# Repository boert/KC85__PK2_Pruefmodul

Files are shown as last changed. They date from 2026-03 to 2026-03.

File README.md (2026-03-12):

# KC85__PK2_Pruefmodul
Nachentwickelte Leiterplatte zum Prüfmodul PK2 für den KC85/4 aus Mühlhausen.
Bisher ist der Leiterplattenentwurf nicht getestet worden (02/2026).

## Schaltplan
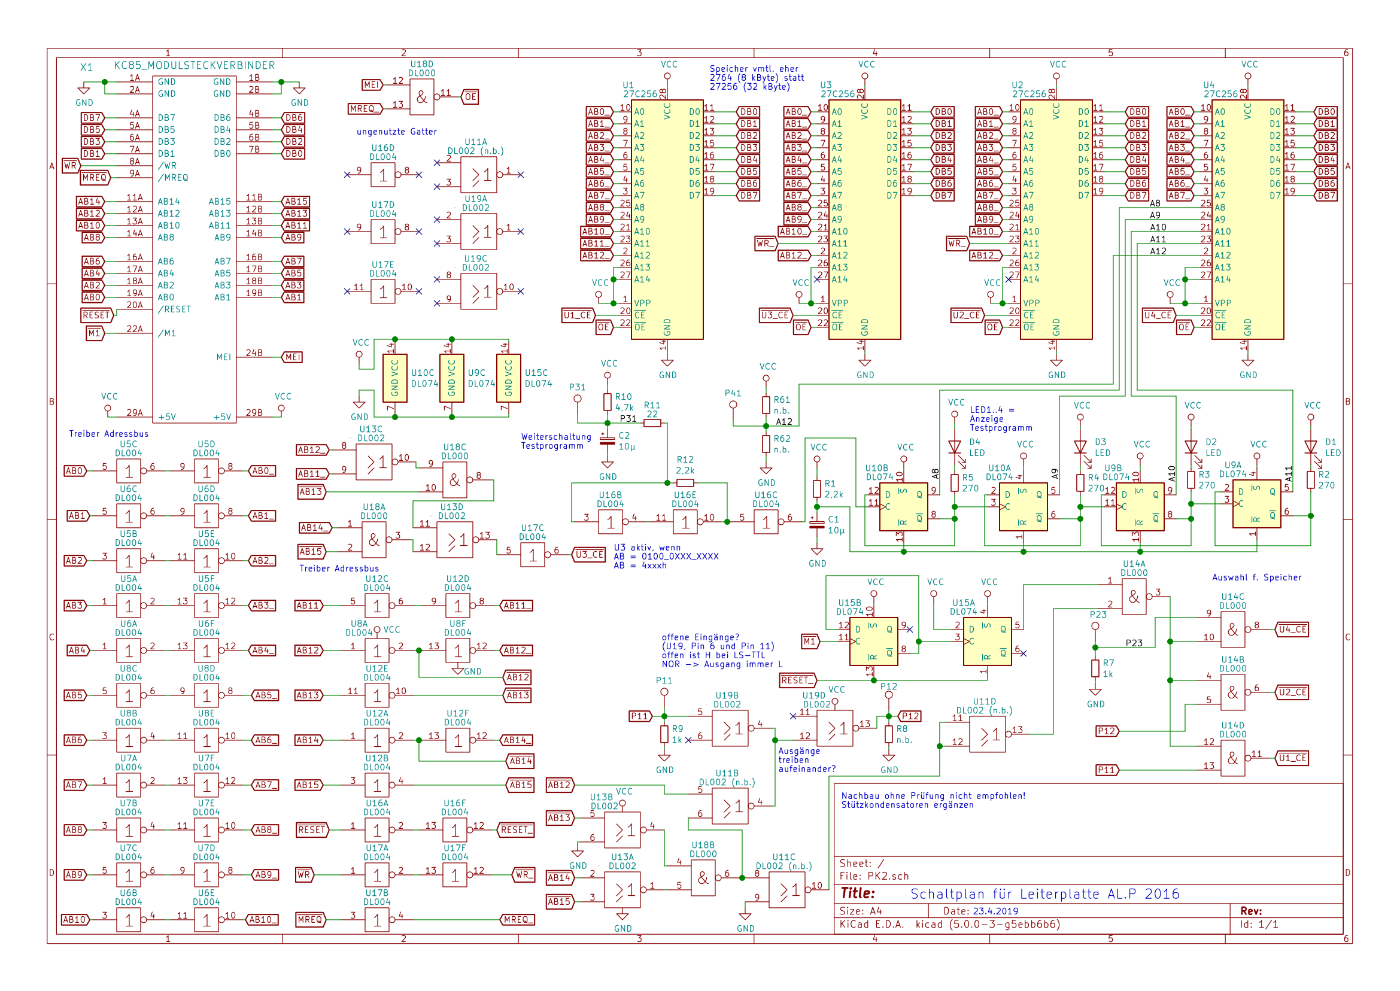
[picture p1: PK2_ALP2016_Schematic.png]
Schaltplan


## Layout
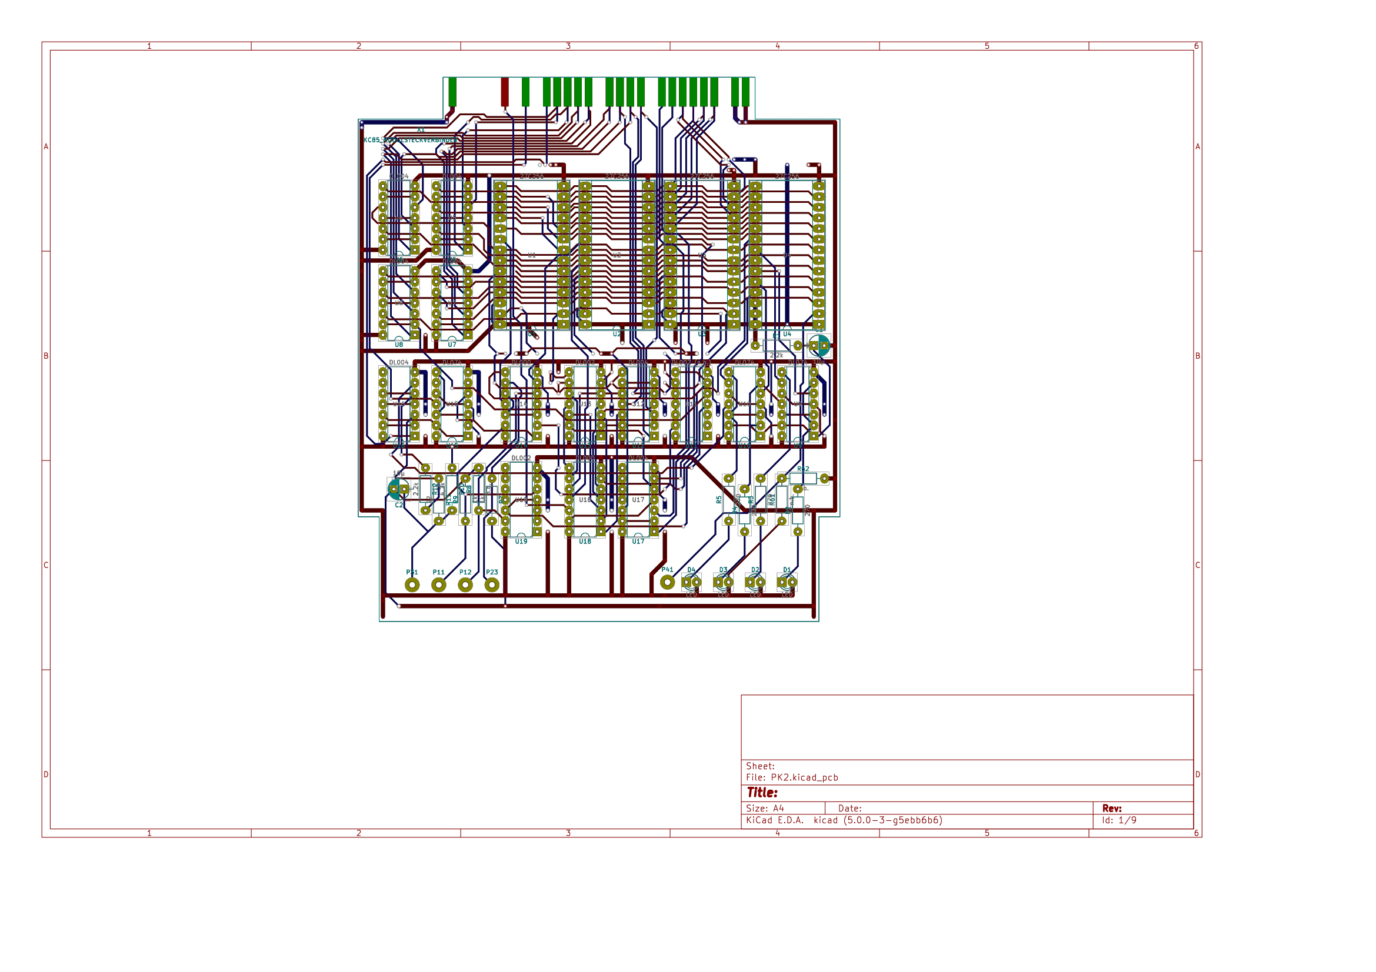
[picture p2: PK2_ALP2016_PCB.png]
Layout


## EPROMs
Ein EPROM enthält das Betriebssystem CAOS 4.2, das andere die 16 in der Anleitung beschriebenen Prüfprogramme.
Die Prüfsumme über den Speicherinhalt wird nach CRC-CCITT (CRC-16) [^1] berechnet:
```
$ jacksum -a crc:16,1021,ffff,false,false,0 -X *.BIN
79D5    8192    Pruefmodul_CAOS_42.BIN
3578    8192    Pruefmodul_P222.BIN
```

Vielen Dank an Andreas, Guido, KaiOr und Ralle für die Vorlagen!

[^1]: [Wikipedia, Zyklische Redundanzprüfung](https://de.wikipedia.org/wiki/Zyklische_Redundanzpr%C3%BCfung)

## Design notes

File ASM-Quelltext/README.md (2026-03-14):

# P222_neu.asm
Die Binärdatei 'P222.BIN' wurde rückübersetzt (Disassmbler[^1]). Zusammen mit den Marken und Kommentaren aus P1.ASM und P2.ASM wurde der Assmbler-Quellcode neu erstellt.
Als Assembler kommt z80asm[^2] zum Einsatz.

Ein Kontrolle der Prüfsummen[^3] ergibt Übereinstimmung mit dem Original:
```
make jacksum

jacksum -a crc:16,1021,ffff,false,false,0 -X ../EPROMs/Pruefmodul_P222.BIN P222_neu.rom
3578    8192    ../EPROMs/Pruefmodul_P222.BIN
3578    8192    P222_neu.rom
```

## Referenzen

[^1]: [Z80-Disassmbler](https://github.com/lvitals/z80dasm/)
[^2]: [Z80-Assembler z80asm](https://www.nongnu.org/z80asm/)
[^3]: [Jacksum, checksum untility](https://jacksum.net/en/index.html)

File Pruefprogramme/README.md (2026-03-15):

# Prüfprogramme

Die Prüfprogramme sind für die Inbetriebnahme des KC85/4 und zur Fehlersuche bei Hardwareproblemen entwickelt worden.
Manche Prüfprogramme (z.B. REGTEST) sind nur sinnvoll mit Messgeräten, wie z.B. einem Oszilloskop, zu gebrauchen.

Die hier abgelegten Prüfprogramme sind aus dem ROM P222.BIN herausgelöst und so angepasst, das direkt im KC lauffähig sind.

## BWS 55H
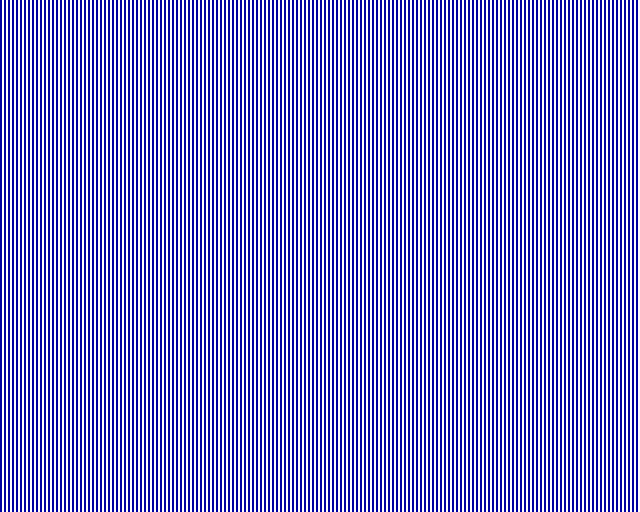
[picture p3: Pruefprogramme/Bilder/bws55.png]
BWS 55H


## Normaltestbild
Dieses Prüfprogramm ermöglicht eine allgemeine Beurteilung
der Farb- sowie Grafiktüchtigkeit des Gerätes.
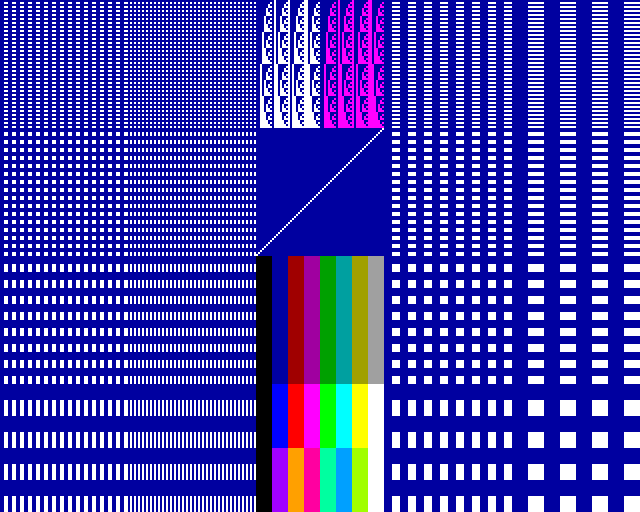
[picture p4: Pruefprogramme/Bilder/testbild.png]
Normaltestbild


## Pixeltestbild
Hier erfolgt eine Darstellung im hochauflösenden Pixelmode des
KC 85/4.
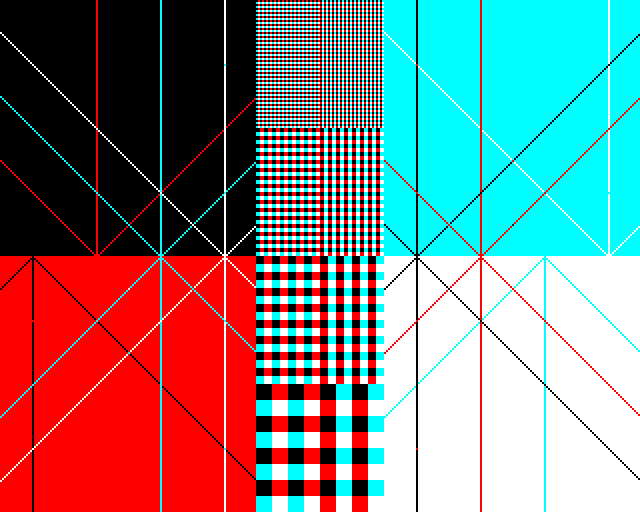
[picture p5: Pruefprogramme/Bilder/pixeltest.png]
Pixeltestbild


## Farbbalken
Dieses Prüfprogramm dient zum Feststellen von Fehlern auf der
Video-Leiterplatte.
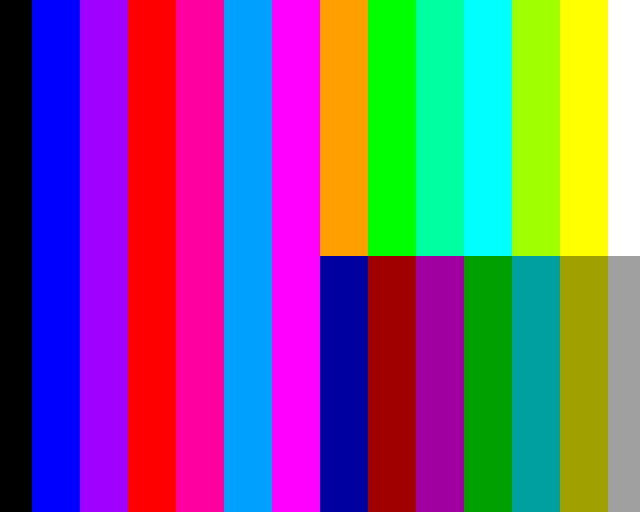
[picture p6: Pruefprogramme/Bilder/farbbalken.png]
Farbbalken


Zum Vergleich das resultierende FBAS-Signal mit dem Oszilloskop aufgenommen:
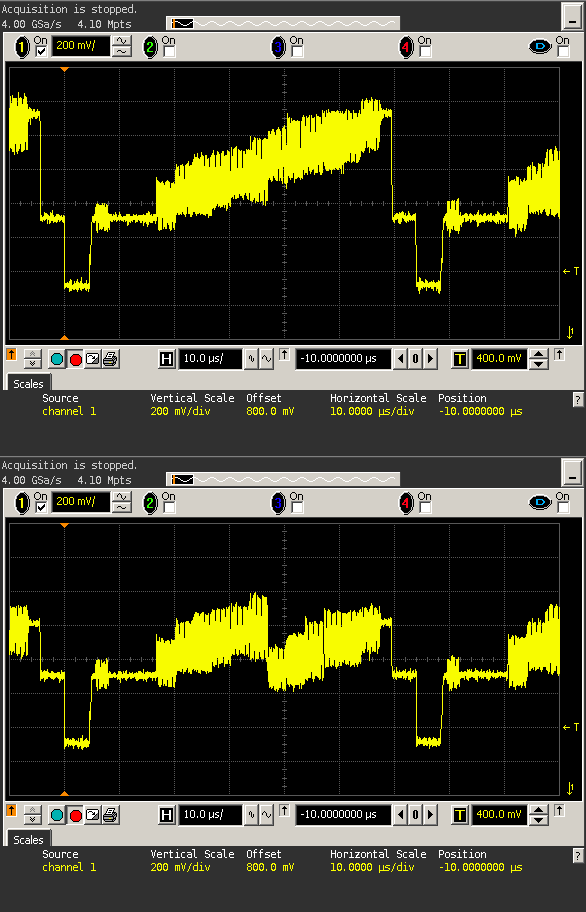
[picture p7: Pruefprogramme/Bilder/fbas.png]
FBAS-Signal


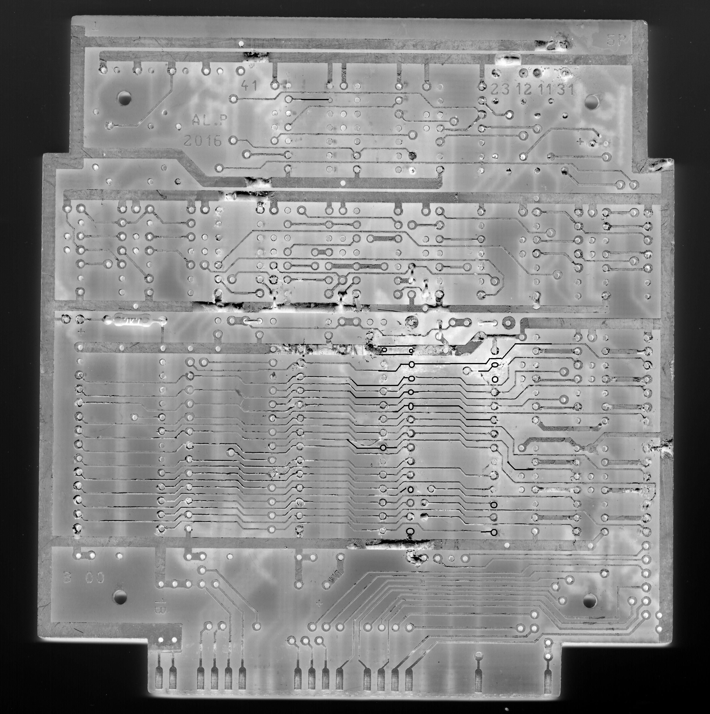
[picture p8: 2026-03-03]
Bilder/Platine_P2016_LS.jpg

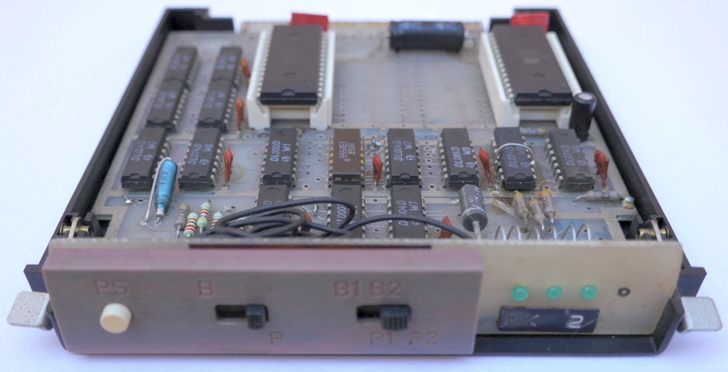
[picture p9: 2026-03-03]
Bilder/Modul_PK2_vorn.jpg

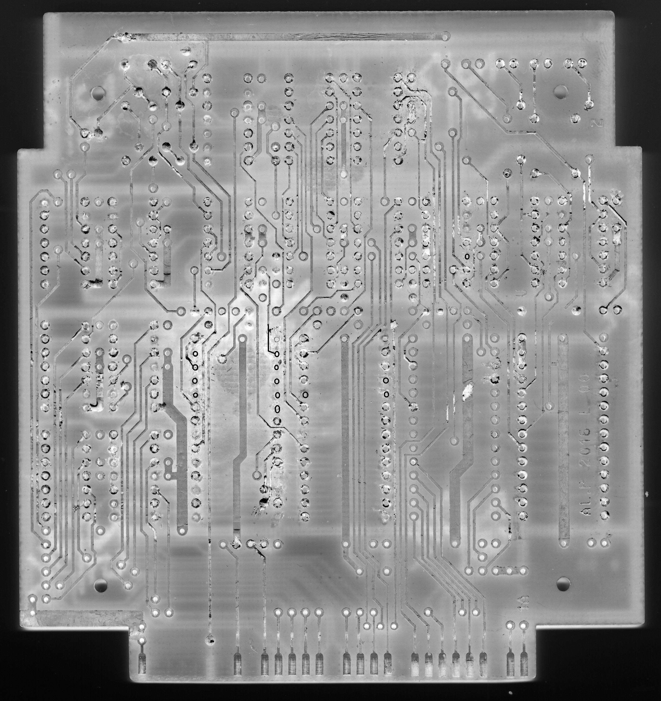
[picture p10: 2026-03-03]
Bilder/Platine_P2016_BS.jpg

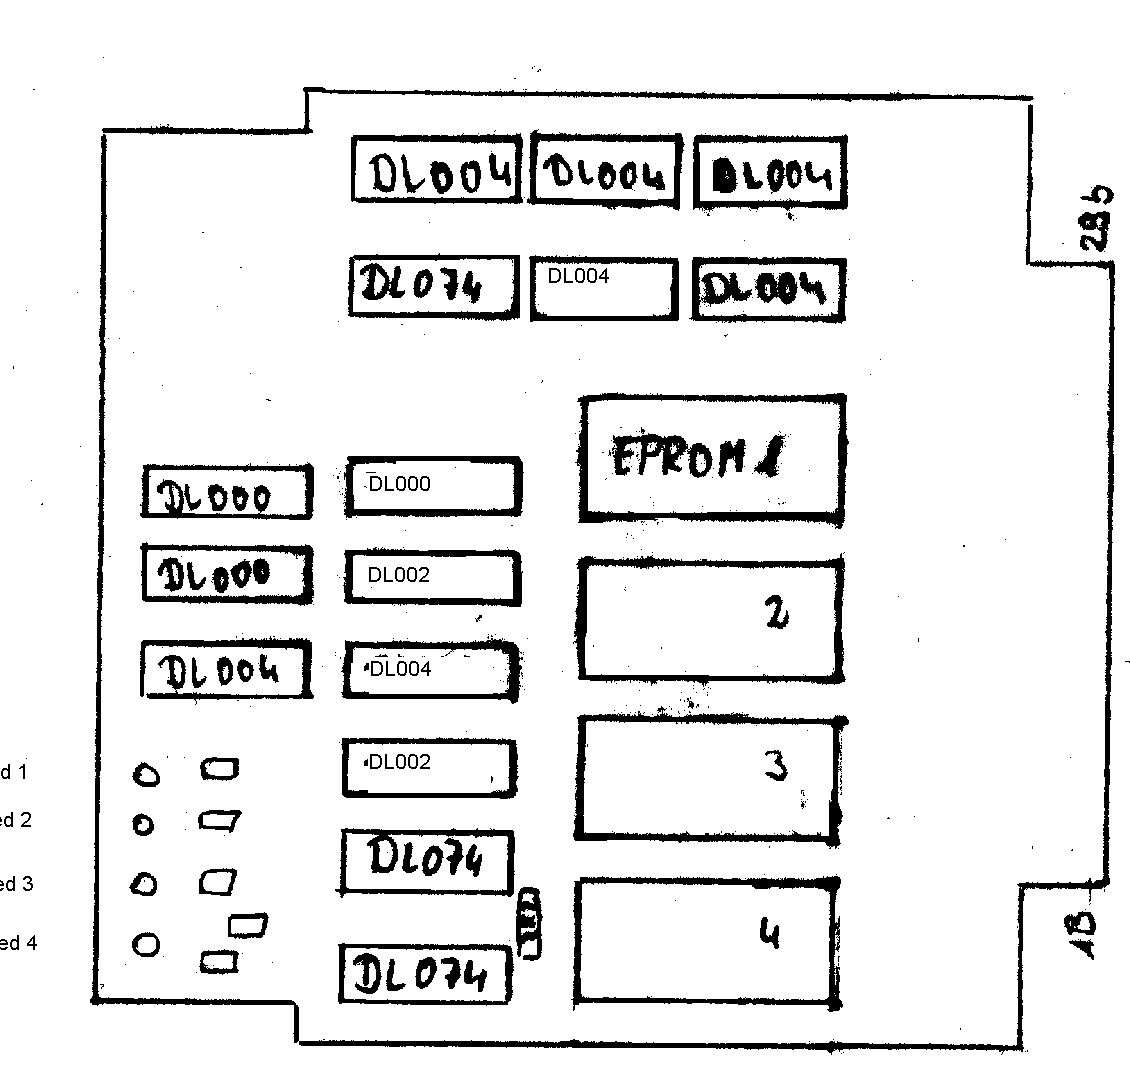
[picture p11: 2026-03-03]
Bilder/Bestueckungsplan.jpg

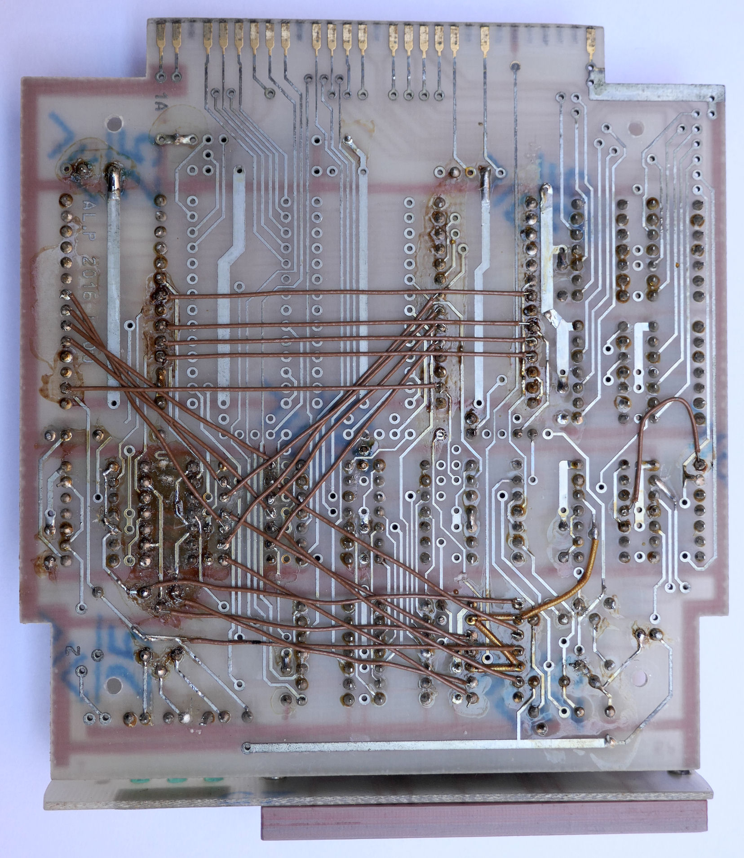
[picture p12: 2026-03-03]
Bilder/Modul_PK2_unten.jpg

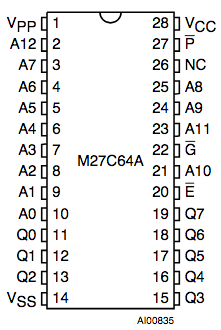
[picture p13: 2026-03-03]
kicad/M27C64.png

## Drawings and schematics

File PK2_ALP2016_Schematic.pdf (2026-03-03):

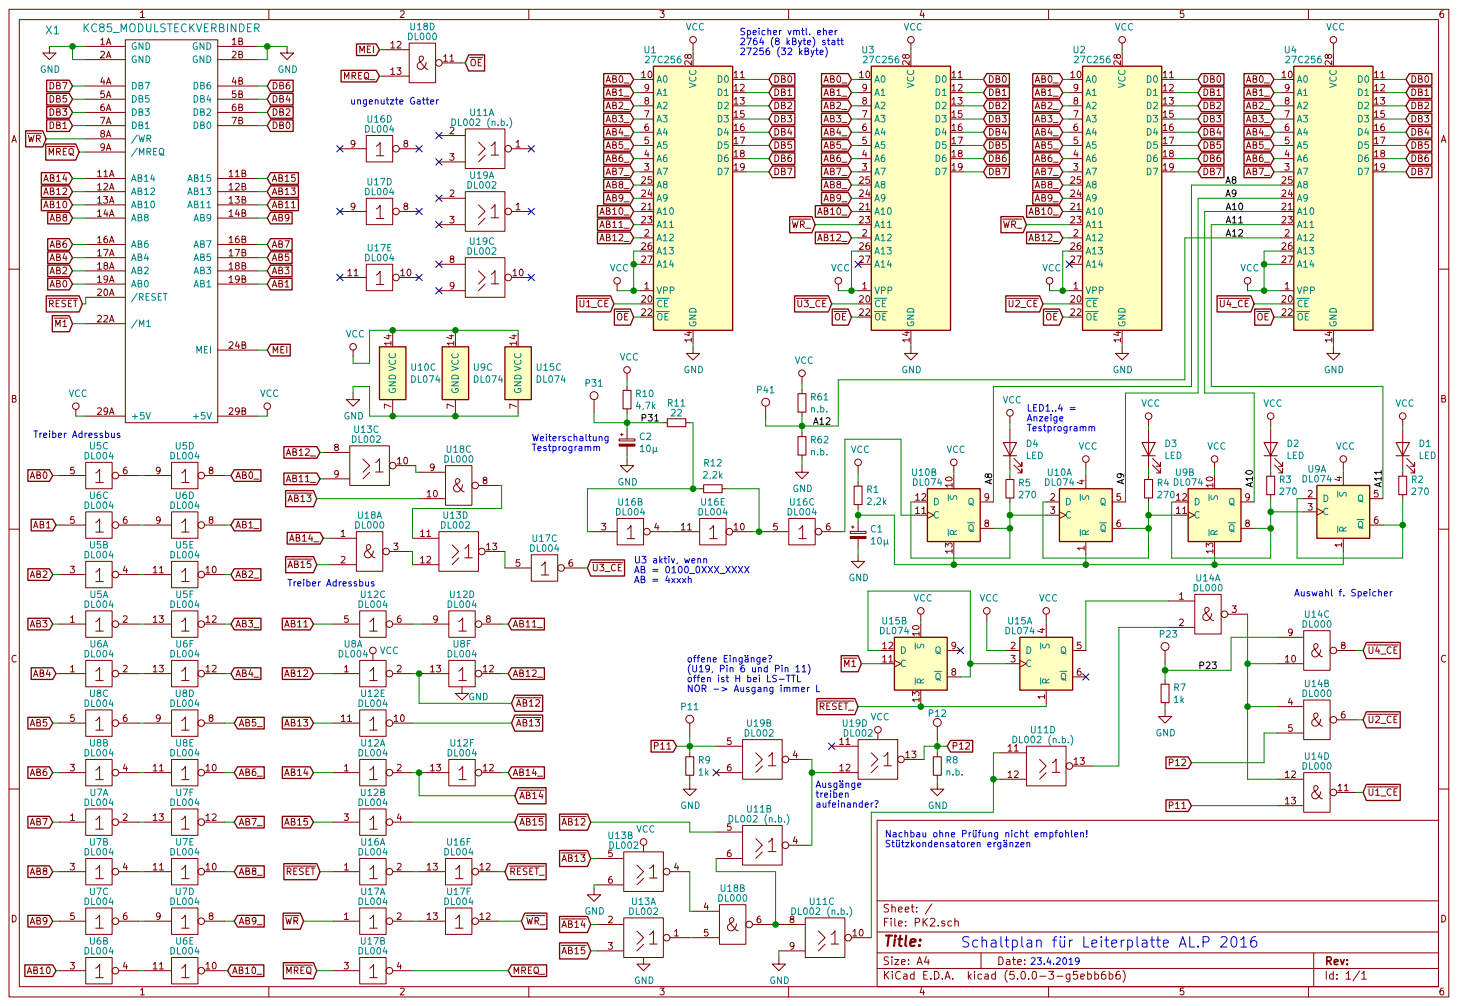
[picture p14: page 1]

offene Eingänge?
(U19, Pin 6 und Pin 11) offen ist H bei LS-TTL NOR -> Ausgang immer L

Nachbau ohne Prüfung nicht empfohlen!
Stützkondensatoren ergänzen

Id: 1/1 Title: File: PK2.sch Sheet: /

Schaltplan für Leiterplatte AL.P 2016

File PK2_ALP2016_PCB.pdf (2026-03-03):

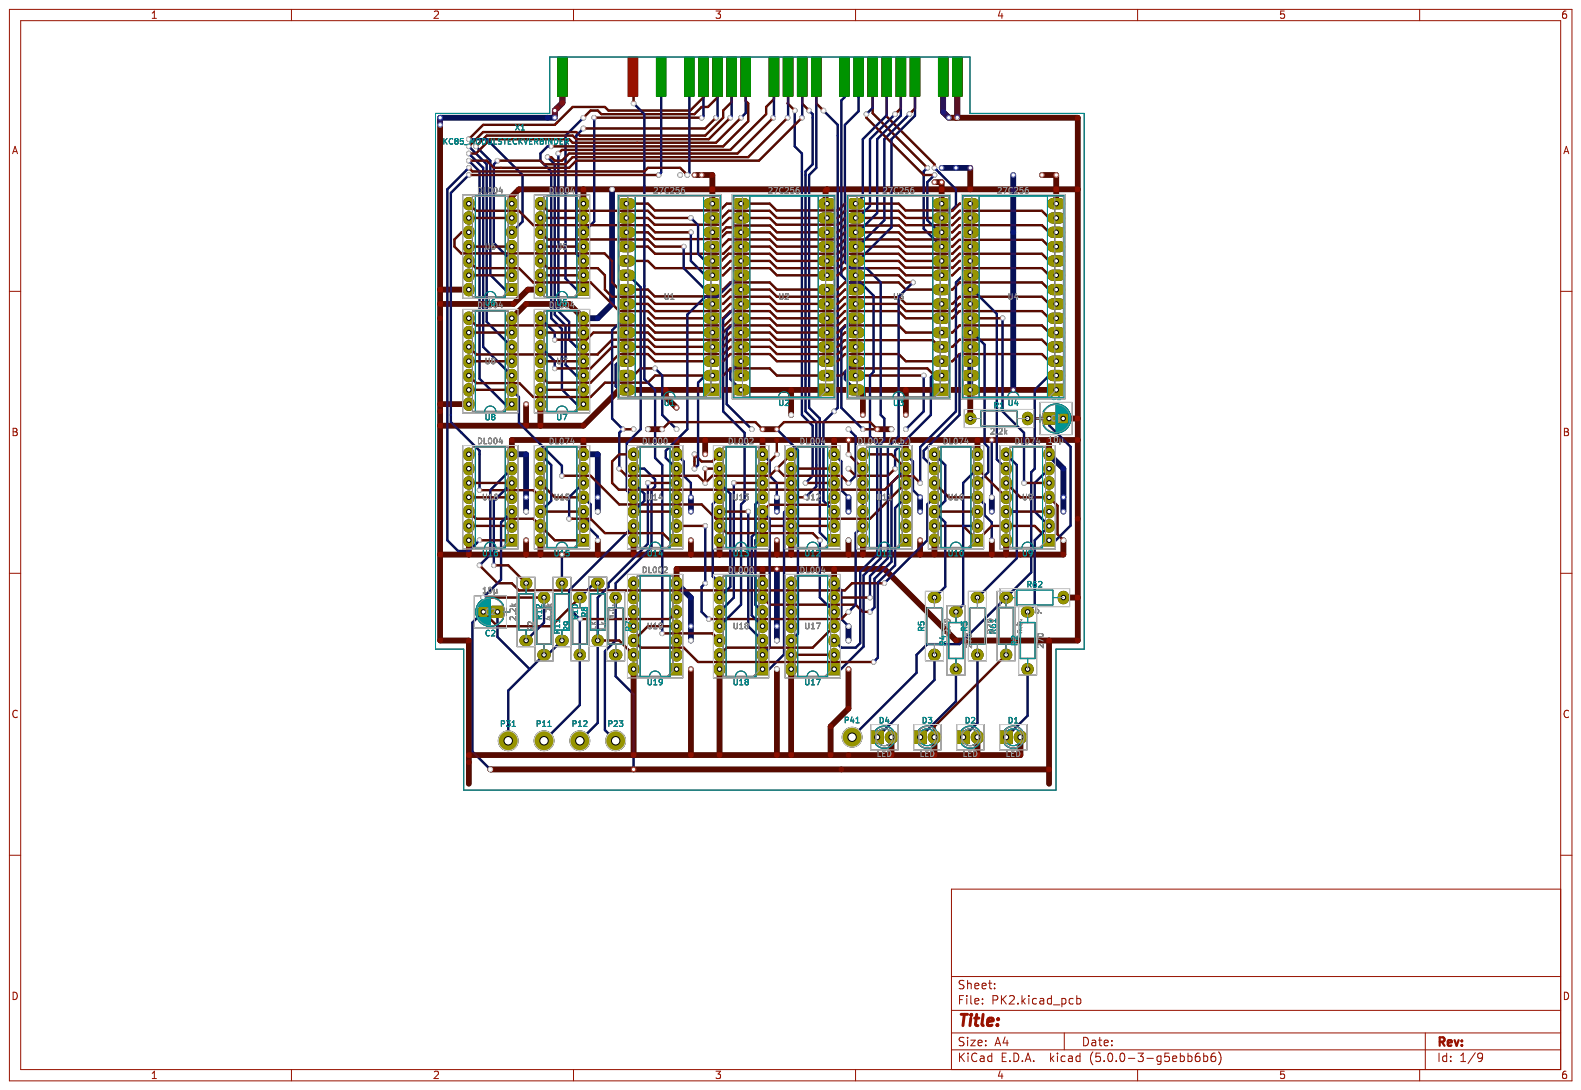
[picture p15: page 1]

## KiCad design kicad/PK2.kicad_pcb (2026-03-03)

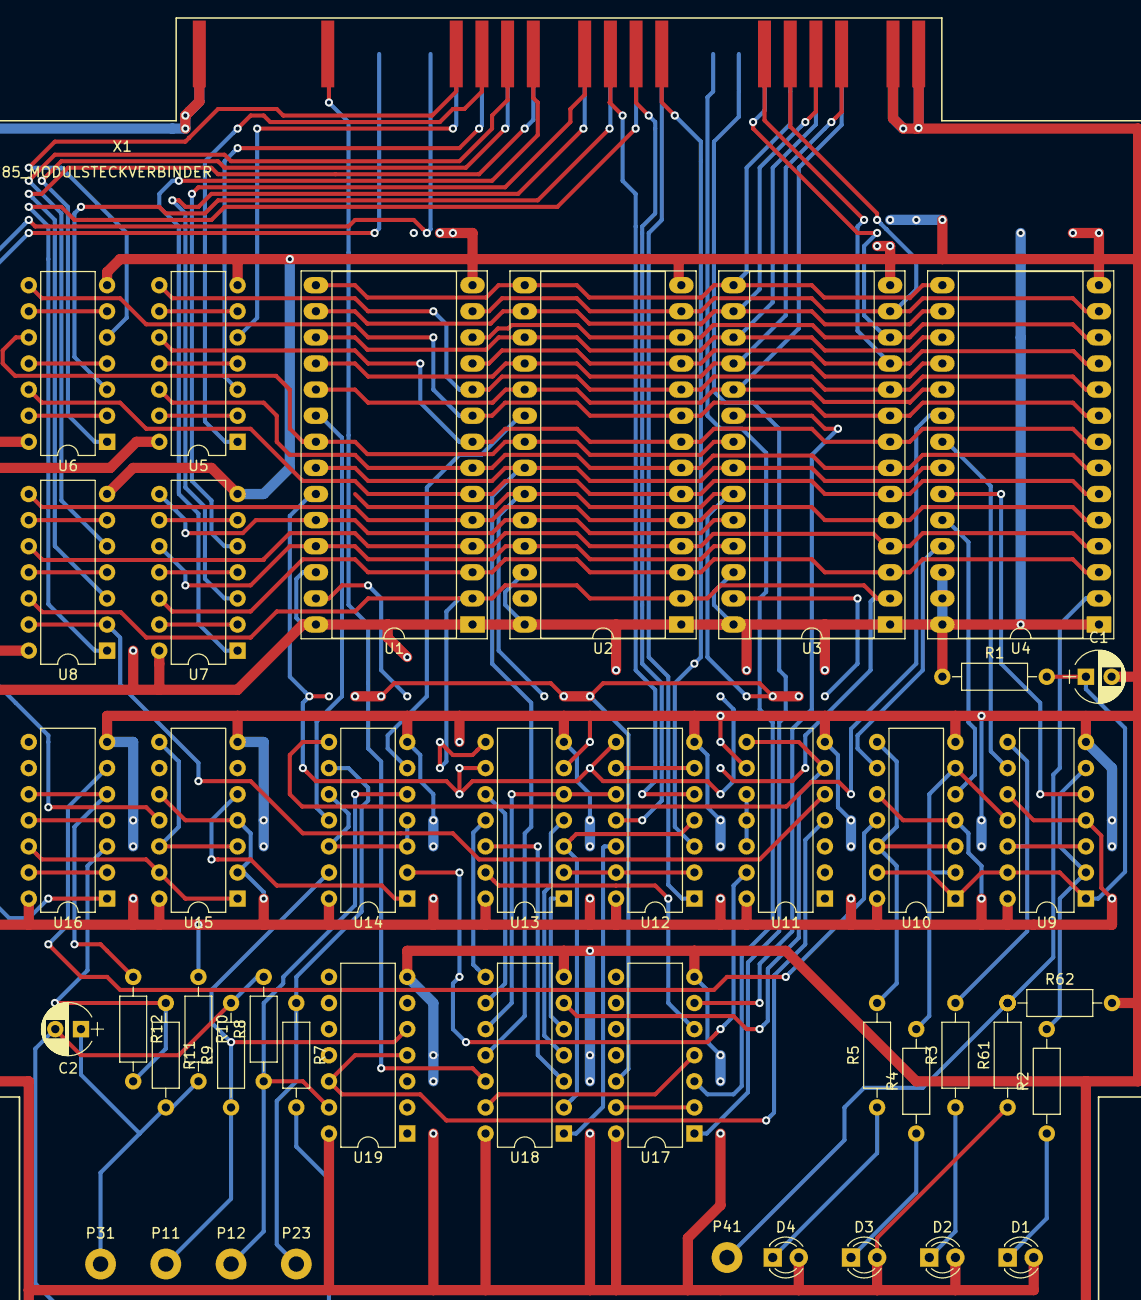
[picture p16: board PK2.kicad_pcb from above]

Board: 2 copper layers, 44 parts (0 on the bottom side), 106 nets.

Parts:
C1, C2: 10µ; CP_Radial_D5.0mm_P2.50mm
D1, D2, D3, D4: LED; LED_D3.0mm
P11, P12, P23, P31, P41: TestPoint; Measurement_Point_Round-TH_Big
R1, R12: 2,2k; R_Axial_DIN0207_L6.3mm_D2.5mm_P10.16mm_Horizontal
R2, R3, R4, R5: 270; R_Axial_DIN0207_L6.3mm_D2.5mm_P10.16mm_Horizontal
R7, R9: 1k; R_Axial_DIN0207_L6.3mm_D2.5mm_P10.16mm_Horizontal
R8, R61, R62: n.b.; R_Axial_DIN0207_L6.3mm_D2.5mm_P10.16mm_Horizontal
R10: 4,7k; R_Axial_DIN0207_L6.3mm_D2.5mm_P10.16mm_Horizontal
R11: 22; R_Axial_DIN0207_L6.3mm_D2.5mm_P10.16mm_Horizontal
U1, U2, U3, U4: 27C256; DIP-28_W15.24mm_Socket_LongPads
U5, U6, U7, U8, U12, U16, U17: DL004; DIP-14_W7.62mm
U9, U10, U15: DL074; DIP-14_W7.62mm
U11: DL002 (n.b.); DIP-14_W7.62mm
U13, U19: DL002; DIP-14_W7.62mm
U14, U18: DL000; DIP-14_W7.62mm
X1: KC85_MODULSTECKVERBINDER; KC85_Modul

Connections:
/A8: U4.25, U10.9
/A9: U4.24, U10.5
/A10: U4.21, U9.9
/A11: U4.23, U9.5
/A12: P41.1, R61.2, R62.1, U4.2
/P23: P23.1, R7.1, U14.9
/P31: C2.1, P31.1, R10.2, R11.2
AB0: U5.5, X1.19A
AB0_: U1.10, U2.10, U3.10, U4.10, U5.8
AB1: U6.5, X1.19B
AB1_: U1.9, U2.9, U3.9, U4.9, U6.8
AB2: U5.3, X1.18A
AB2_: U1.8, U2.8, U3.8, U4.8, U5.10
AB3: U5.1, X1.18B
AB3_: U1.7, U2.7, U3.7, U4.7, U5.12
AB4: U6.1, X1.17A
AB4_: U1.6, U2.6, U3.6, U4.6, U6.12
AB5: U8.5, X1.17B
AB5_: U1.5, U2.5, U3.5, U4.5, U8.8
AB6: U8.3, X1.16A
AB6_: U1.4, U2.4, U3.4, U4.4, U8.10
AB7: U7.1, X1.16B
AB7_: U1.3, U2.3, U3.3, U4.3, U7.12
AB8: U7.3, X1.14A
AB8_: U1.25, U2.25, U3.25, U7.10
AB9: U7.5, X1.14B
AB9_: U1.24, U2.24, U3.24, U7.8
AB10: U6.3, X1.13A
AB10_: U1.21, U2.21, U3.21, U6.10
AB11: U12.5, X1.13B
AB11_: U1.23, U12.8, U13.9
AB12: U8.1, X1.12A
AB12_: U1.2, U2.2, U3.2, U8.12, U13.8
AB13: U12.11, X1.12B
AB14: U12.1, X1.11A
AB14_: U12.12, U18.1
AB15: U12.3, X1.11B
DB0: U1.11, U2.11, U3.11, U4.11, X1.7B
DB1: U1.12, U2.12, U3.12, U4.12, X1.7A
DB2: U1.13, U2.13, U3.13, U4.13, X1.6B
DB3: U1.15, U2.15, U3.15, U4.15, X1.6A
DB4: U1.16, U2.16, U3.16, U4.16, X1.5B
DB5: U1.17, U2.17, U3.17, U4.17, X1.5A
DB6: U1.18, U2.18, U3.18, U4.18, X1.4B
DB7: U1.19, U2.19, U3.19, U4.19, X1.4A
GND: C1.2, C2.2, R7.2, R8.2, R9.2, R62.2, U1.14, U2.14, U3.14, U4.14, U5.7, U6.7, U7.7, U8.7, U9.7, U10.7, U11.7, U11.9, U12.7, U13.6, U13.7, U14.7, U15.7, U16.7, U17.7, U18.7, U19.7, X1.1A, X1.1B, X1.2A, X1.2B
MEI: U18.12, X1.24B
MREQ_: U17.4, U18.13
unnamed: C1.1, R1.2, U9.1, U9.13, U10.1, U10.13
unnamed: D1.1, R2.1
unnamed: D2.1, R3.1
unnamed: D3.1, R4.1
unnamed: D4.1, R5.1
unnamed: R2.2, U9.2, U9.6
unnamed: R3.2, U9.3, U9.8, U9.12
unnamed: R4.2, U9.11, U10.2, U10.6
unnamed: R5.2, U10.3, U10.8, U10.12
unnamed: R11.1, R12.2, U16.3
unnamed: R12.1, U16.5, U16.10
unnamed: U5.6, U5.9
unnamed: U5.4, U5.11
unnamed: U5.2, U5.13
unnamed: U6.6, U6.9
unnamed: U6.4, U6.11
unnamed: U6.2, U6.13
unnamed: U7.6, U7.9
unnamed: U7.4, U7.11
unnamed: U7.2, U7.13
unnamed: U8.6, U8.9
unnamed: U8.4, U8.11
unnamed: U10.11, U16.6
unnamed: U11.4, U19.4, U19.12
unnamed: U11.6, U11.8, U18.6
unnamed: U11.10, U11.11, U11.12
unnamed: U11.13, U14.2
unnamed: U12.6, U12.9
unnamed: U13.1, U18.5
unnamed: U13.4, U18.4
unnamed: U13.10, U18.9
unnamed: U13.11, U18.8
unnamed: U13.12, U18.3
unnamed: U13.13, U17.5
unnamed: U14.1, U15.5
unnamed: U14.3, U14.4, U14.10, U14.12
unnamed: U15.3, U15.8, U15.12
unnamed: U16.4, U16.11
unnamed: U16.2, U16.13
unnamed: U17.2, U17.13
P11: P11.1, R9.1, U14.13, U19.5
P12: P12.1, R8.1, U14.5, U19.13
VCC: D1.2, D2.2, D3.2, D4.2, R1.1, R10.1, R61.1, U1.1, U1.26, U1.27, U1.28, U2.1, U2.26, U2.28, U3.1, U3.26, U3.28, U4.1, U4.26, U4.27, U4.28, U5.14, U6.14, U7.14, U8.14, U9.4, U9.10, U9.14, U10.4, U10.10, U10.14, U11.14, U12.14, U13.14, U14.14, U15.2, U15.4, U15.10, U15.14, U16.14, U17.14, U18.14, U19.14, X1.29A, X1.29B
~AB12: U8.2, U8.13, U11.5
~AB13: U12.10, U13.5, U18.10
~AB14: U12.2, U12.13, U13.2
~AB15: U12.4, U13.3, U18.2
~M1: U15.11, X1.22A
~MREQ: U17.3, X1.9A
~OE: U1.22, U2.22, U3.22, U4.22, U18.11
~RESET: U16.1, X1.20A
~RESET_: U15.1, U15.13, U16.12
~U1_CE: U1.20, U14.11
~U2_CE: U2.20, U14.6
~U3_CE: U3.20, U17.6
~U4_CE: U4.20, U14.8
~WR: U17.1, X1.8A
~WR_: U2.23, U3.23, U17.12

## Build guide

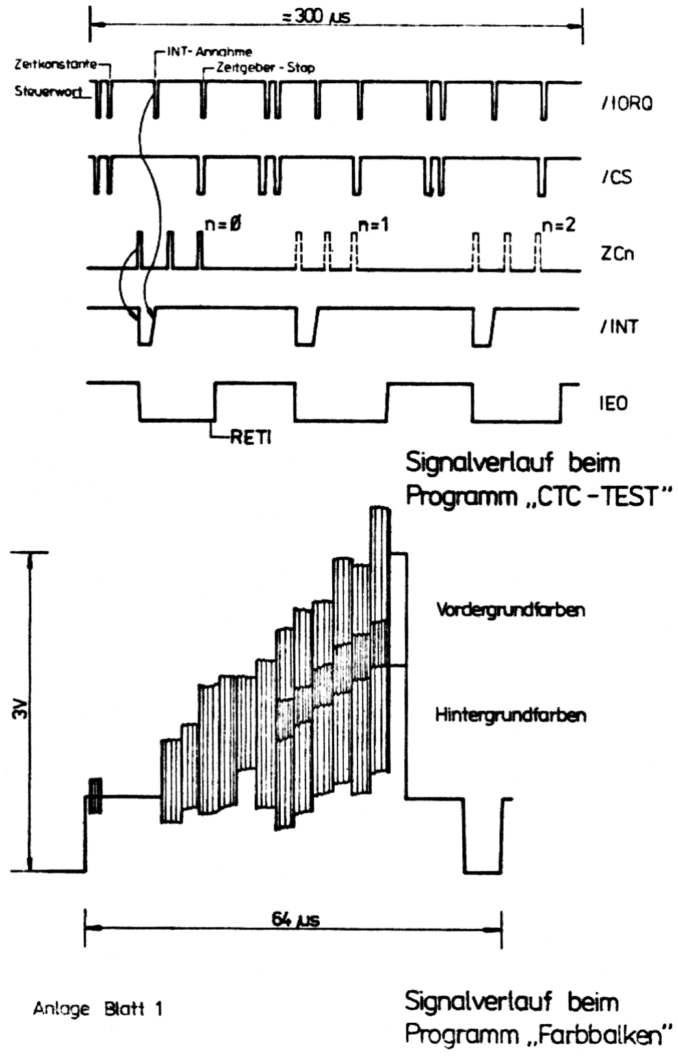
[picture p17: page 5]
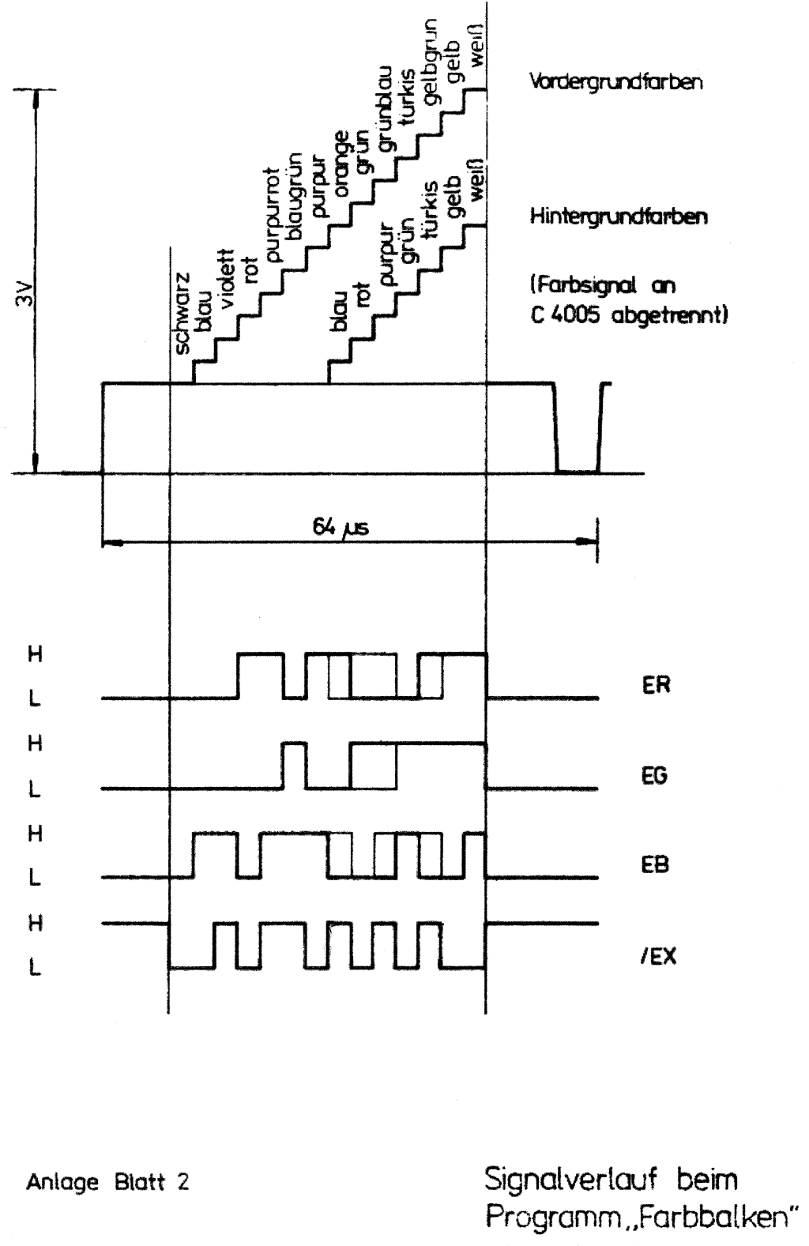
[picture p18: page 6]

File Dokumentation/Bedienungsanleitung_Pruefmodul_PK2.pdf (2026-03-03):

BEDIENUNGSANLEITUNG ZUM REPARATURMODUL PK2 FÜR KC 85/4 ------------------------------------------------------
EPROM P222 | CHSUM 3578 | STAND 27.01.89

Dieser Modul dient dazu, Fehler bei der Inbetriebnahme oder der Reparatur des KC 85/4 zu erkennen und deren Lokalisierung zu unterstützen. Dazu muß der interne ROM des KC 85/4 (Adreßbereich E000-FFFF) inaktiv geschalten werden, wozu die ober-
halb | der | PIO | liegende | Lötbrücke | RB3003 | dient, | die | im
Reparaturfall zu schließen ist. Der Modul kann im Schacht 8 oder C betrieben werden. Auf ihm befinden sich das Betriebssystem (ROM E) und die unten aufgeführten Prüfprogramme. Über den linken Schalter kann zwischen dem Betriebssystem (B) und
den | Prüfprogrammen | (P) | gewählt | werden | (in | Mittelstellung
beides inaktiv).
Mit dem rechten Schalter können die beiden Gruppen von Prüf-
programmen | (P1, | P2) | und | die | Freigabe | für | das | externe
Betriebssystem (B1) geschalten werden. In jeder Gruppe von
Prüfprogrammen | können | acht | Programme | über | den | Taster
fortlaufend angewählt werden, wobei die Leuchtdioden das angewählte Programm unabhängig vom Bildschirm angeben.
Bei der Reparatur ist zu beachten, daß einige Programme den
BWS | als | Arbeits-RAM | benutzen | (Stack, | Interruptvektoren).
Deshalb muß zuerst der BWS untersucht und seine Funktion hergestellt werden. Dazu dienen die Programme 0 bis 5 von P1, die ohne Arbeits-RAM ablaufen.
S C H A L T E R S T E L L U N G | P1 S C H A L T E R S T E L L U N G | P1
Programm 0 | “REGISTERTEST”: Programm 0 | “REGISTERTEST”:
An beiden Registern DL374 (D3008,D3009) werden decremetierende Werte zur oszillographischen Kontrolle ausgegeben. Dabei entstehen an den Ausgängen Rechteckspannungen, die mit dem Oszillographen kontrolliert werden können. An Bit 0 entsteht dabei die höchste Frequenz; am nächst höheren Bit jeweils die halbe Frequenz des vorhergehenden Bits. Dadurch ist die Überprüfung der CLK-Signale am Pin 11 der Register sowie aller Ausgänge möglich. Durch die Bedeutung der Registerausgänge in der Schaltung ergibt sich auf dem Bildschirm ein blaues Karomuster, welches von oben nach unten durchrollt.
:
LD B,0
MAR: LD A,B
OUT 84H | ;Register 1
OUT 86H | ;Register 2
DJNZ MAR ;255-0
JR MAR
Programm 1 | “PIOTEST”: Programm 1 | “PIOTEST”:
Beim Testen der KC-internen PIO werden auf beide Kanäle analog dem Programm “REGISTERTEST” decrementierende Werte ausgegeben. (Bit A0 ist durch das Inaktivieren des ROM E (D3210) mittels RB 3003 ständig Low!)

:
LD B,0
MAR: LD A,B
OUT 88H | ;Port A
OUT 89H | ;Port B
DJNZ MAR ;255-0
JR MAR
Programm 2 | “BWS 55H”: Programm 2 | “BWS 55H”:
Beschreiben des Bildwiederholspeichers mit 55H. An den Schaltkreisen kann das Weiterreichen des Datenbytes mit dem Oszillographen kontrolliert werden, wobei zu beachten ist, daß die Datenein-und –ausgänge des BWS nicht verbunden sind und der VTG ebenfalls zugreift. Auf dem Bildschirm müssen pixelbreite Streifen entstehen.
:
LD A,55H
MAR: LD HL,8000H
LD DE,8001H
LD BC,3FFFH
LD (HL),A
LDIR
JR MAR
Programm 3 | “BWS AAH”: Programm 3 | “BWS AAH”:
Beschreiben | des | Bildwiederholspeichers | mit | AAH. | Auf | dem
Bildschirm entsteht das invertierte Bild von “BWS 55H”.
Programm 4 | “RAM 55H”: Programm 4 | “RAM 55H”:
Bei diesem Testprogramm wird der Arbeits-RAM 0-BFFFH zyklisch mit 55H beschrieben. Dabei können das Hochzählen der Adressen
und | das | Weiterreichen | des | Datenbytes | oszillographisch
kontrolliert werden.
:
LD A,55H
MAR: LD HL,0
LD DE,1
LD BC,0BFFFH
LD (HL),A
LDIR
JR MAR
Programm 5 | “RAM AAH”: Programm 5 | “RAM AAH”:
Beschreiben des Arbeits-RAMs mit AAH. (s.o.)
Programm 6 | “CTC- Programm 6 | “CTC-TEST”:
Der Test der CTC erfolgt indem die Kanäle K0 bis K2 als Zeit-
geber mit der | Zeitkonstante | 2 | interruptfähig | programmiert
werden. An den Ausgängen ZC0 bis ZC2 entstehen Nulldurchgangsimpulse, die einen Interrupt auslösen. Die Interruptannahme der CPU wird über eine Warteschleife, in der sich die CPU im DI befindet, verzögert, sodaß am Pin 12 (INT) deutliche Impulse sichtbar werden. In der INT-Serviceroutine werden die
Kanäle | ausgeschaltet | um | dann | im | nächsten | Zyklus | erneut
programmiert zu werden. Damit können auch die Steuersignale der CTC kontrolliert werden. (siehe Anhang)

Programm 7 | “RAMVERKOPPLUNG”: Programm 7 | “RAMVERKOPPLUNG”: 7 | “RAMVERKOPPLUNG”:
In diesem Programm werden die niederwertigen Adressen des Busses (A0...A13) auf Verkopplungen getestet. Dabei wird auf Byte 0000 eine 55H eingetragen und der zuvor gelöschte Bereich 1 bis 4000H nach einem weiteren Auftreten der 55H durchsucht. Die fehlerhaften Adreßbits werden angezeigt.
Anschließend erfolgt ein Blocktest, d.h. am Anfang eines jeden 16k-Blockes des internen 64k-RAMs werden spezifische Bytes eingetragen. Falls diese Bytes in einem anderen Block auftauchen, wird dieser Block als fehlerhaft gemeldet.
Im dritten Teil dieses Programmes wird jeder Block des 64k Arbeits-RAMs auf fehlerhafte Bits untersucht. Der Block wird dabei mit einer Bytefolge von 55H und AAH beschrieben und nach etwa 6ms auf den Dateninhalt getestet. Danach wird derselbe Zyklus mit der Bytefolge AAH und 55H wiederholt. Bei fehlerhaften Datenbits bleibt der Rechner im Schreib-/Lesezyklus auf dieser Adresse mit dem jeweils fehlerhaften Datenbyte.
:
LD A,xx | ;55H oder AAH
| | MAR: LD M,A | ;Schreiben
| | LD C,M | ;Lesen
| | JR MAR
S C H A L T E R S T E L L U N G | P2 S C H A L T E R S T E L L U N G | P2
Programm 0 | “NORMALTESTBILD”: Programm 0 | “NORMALTESTBILD”:
Dieses Prüfprogramm ermöglicht | eine allgemeine | Beurteilung
der Farb- sowie Grafiktüchtigkeit des Gerätes. Das erzeugte Testbild enthält quadratische Felder mit unterschiedlichen Abständen zwischen den gesetzten Pixeln. In der Mitte des
Bildes | sind | Farbbalken, | schräge | Linie | und | Blinkfeld
dargestellt. Die rechte violette Hälfte des Blinkfeldes muß im 0,5-sec.-Takt blinken. Die schräge Linie verläuft von der linken unteren Ecke des Quadrates zur rechten oberen.
Das nächste Feld stellt die acht Hintergrundfarben dar (von links nach rechts): Schwarz, Blau, Rot, Purpur, Grün, Türkis, Gelb und Weiß.
Das Feld für die Vordergrundfarbe ist geteilt:
Oben: Schwarz, Blau, Rot, Purpur, Grün, Türkis, Gelb, Weiß. Unten: Schwarz, Violett, Orange, Purpurrot, Grünblau, Blau-grün, Gelbgrün, Weiß.
Programm 1 | “PIXELTESTBILD”: Programm 1 | “PIXELTESTBILD”:
Hier erfolgt eine Darstellung im hochauflösenden Pixelmode des KC 85/4. In diesem Bild muß die Möglichkeit, benachbarte Bildpunkte farblich unterschiedlich darzustellen, überprüft werden. Es können die Farben Schwarz, Rot, Türkis und Weiß dargestellt werden. In vier Felder mit je einer dieser Farben werden schräge Linien in allen vier Farben geschrieben. Diese
Linien | dürfen | nur | im | Pixel | der | Kreuzungspunkte | von | der
Linienfarbe abweichen.
Programm 2 | “FARBBALKEN”: Programm 2 | “FARBBALKEN”:
Dieses Prüfprogramm dient zum Feststellen von Fehlern auf der Video-Leiterplatte. Es ermöglicht die oszillographische Kontrolle der Graustufen sowie des Farbsignals am FBAS-Signal des Computers. Die Farben wurden so zusammengestellt, daß sich
eine | aufsteigende | Treppe | der | Graustufen | für | Vorder- | und

Hintergrund ergibt. Durch die unterschiedliche Größe der Farbträger ergibt sich kein sehr aussagekräftiges Bild über die Graustufung innerhalb einer Zeile. Das erhält man bei abgetrenntem Farbsignal (C4005 abtrennen). Diese beiden Bilder sowie das entsprechende R- G- B- und Ex-Signal werden im Anhang dargestellt.

Programm 3 | “RAMTEST”: Programm 3 | “RAMTEST”:
Der gesamte Arbeits-RAM (0 bis 7FFFH und RAM-Floppy) wird auf
korrektes | Schreiben | und | Lesen | sowie | auf | funktionierenden
Schreibschutz getestet. Der nicht sichtbare Bildspeicher (Bild
1) wird nur auf Schreiben/Lesen (ohne Schreibschutz) geprüft.
Programm 4 | “PRÜFSUMME”: Programm 4 | “PRÜFSUMME”: SUMME”:
Hier werden die internen ROMs CAOS C und BASIC (der CAOS-E ROM ist ja über RB 3003 abgeschaltet) innerhalb eines Prüfsummenpolynoms gelesen und diese Prüfsumme dann mit den im CAOS-C ROM abgespeicherten Prüfsummen verglichen. Diese Prüfsummen stehen am Ende des CAOS-C ROMs:
CAOS 4.0: 0CFFAH: | ROM C = 551CH | (gesamt: 2E8AH)
0CFFCH: | BASIC = 1C01H
0CFFEH: | ROM E = E38EH
CAOS 4.1: 0CFFAH: | ROM C = 6637H | (gesamt: 6AB3H)
0CFFCH: | BASIC = 1C01H
0CFFEH: | ROM E = 2BCEH
CAOS 4.2: 0CFFAH: | ROM C = 985CH | (gesamt: 47F5H)
0CFFCH: | BASIC = 1C01H
0CFFEH: | ROM E = 79D5H

Nach diesem Test bleibt der Rechner in einer Leseschleife auf der Adresse D555H (alternierende Adreßbits) wobei wechselseitig am CAOS-C und BASIC-ROM CS-Signale generiert werden (da AB12 nicht extra ausdecodiert wird, entstehen auch am CAOS-C-ROM CS-Signale).
:
LD HL,0D555H
LD A,0E0H
MAR: XOR 80H
OUT 86H | ;CAOS-C ON/OFF
LD D,M | ;Lesen
JR MAR

Programm 5 “ Programm 5 “TONTEST TONTEST TONTEST”:
Dieses Programm erlaubt eine akustische Kontrolle der Ton-
ausgabe. | Beide | Kanäle | werden | unterschiedlich | angesteuert,
Kanal 1 mit einer hochlaufenden hohen Tonfolge, Kanal 2 mit einer hochlaufenden tiefen Tonfolge. (Über den eingebauten Piezosummer kann nur Kanal 1 wahrgenommen werden!)
Am Ende der Tonfolge werden die 4 Lautstärkebits einzeln angesteuert, d.h. es ergeben sich 4 unterschiedlich laute Töne, die Rückschlüsse auf die Lautstärkesteuerung zulassen.
Diese | Kontrolle | erfolgt | über | den | TON-Ausgang | am | TV-RGB-
Anschluß des Computers, da unterschiedliche Lautstärke über den eingebauten Summer oder ein angeschlossenes Tonband nicht wiedergegeben wird.
